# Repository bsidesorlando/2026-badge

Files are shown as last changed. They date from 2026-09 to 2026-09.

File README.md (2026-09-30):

# BSides Orlando 2026 Badge

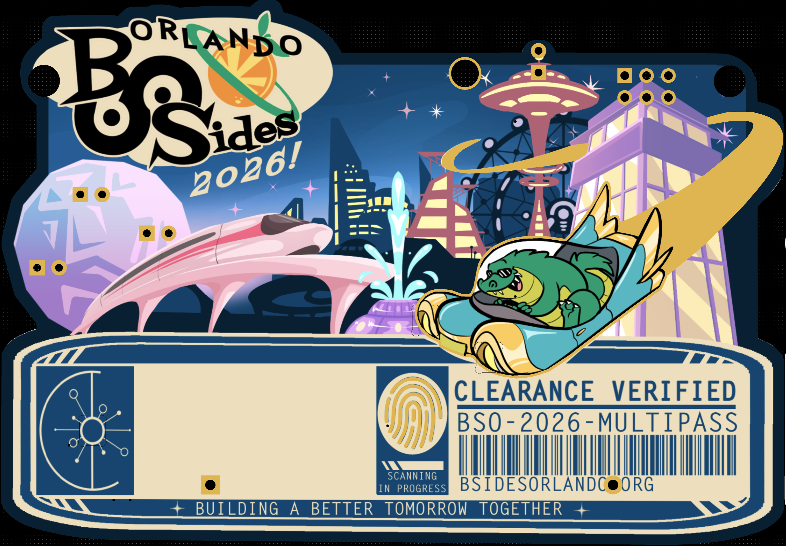
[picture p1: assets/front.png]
Rendering of the front of the BSides Orlando 2026 badge

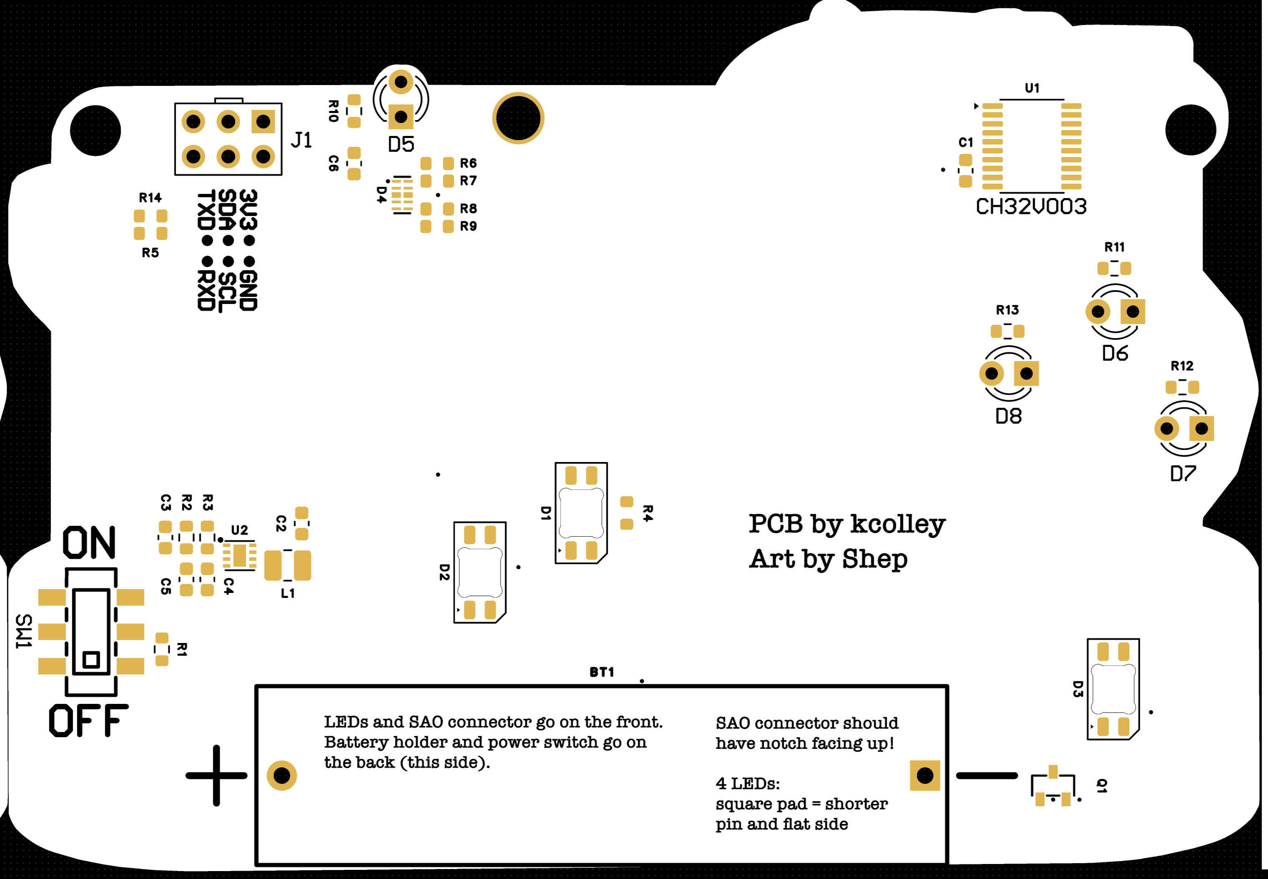
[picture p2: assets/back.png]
Rendering of the back


The electronic badge for BSides Orlando 2026, themed around retro-futurism:
a 1960s World's Fair vision of tomorrow, with Lil Chompy the alligator at
the wheel of a flying car.

- **CH32V003** RISC-V microcontroller, powered by one AAA cell through a
  TPS61021A boost converter.
- **Three SK6812MINI-E RGB LEDs:** the flying car's headlights, and the
  fingerprint scanner indicator.
- **Four self-blinking LEDs:** the tower spire and the geodesic sphere.
- **Two capacitive touch pads:** the fingerprint, and Lil Chompy's head.
- **SAO connector:** the badge is an SAOv3 host on I2C, and GPIO1/GPIO2 carry
  a 115200-baud serial console.
- **Serial console:** runs "Lil Chompy and the World's Fair", a small text
  adventure that doubles as a CTF challenge.

> **Spoilers:** the firmware source contains the CTF solutions and flags.

## Repo layout

| Path | Contents |
| --- | --- |
| `hardware/` | KiCad project (`bsidesorl-v1`), symbol and footprint libraries, and artwork sources |
| `hardware/EasyEDA_Gerber_bsidesorl-v1_2026-08-31.zip` | Gerbers as ordered from JLCPCB |
| `hardware/jlcpcb/` | BOM and CPL as ordered from JLCPCB |
| `hardware/mk_easyeda.py` | Writes an EasyEDA Pro-importable copy of the board |
| `firmware/` | Badge firmware (PlatformIO + [ch32fun](https://github.com/cnlohr/ch32fun)); see [firmware/README.md](firmware/README.md) |

## Firmware quick start

```sh
# saov3-lib's public repo isn't published yet
git submodule update --init

# Build
cd firmware
pio run

# Copy firmware to picorvd-for-badges probe
cp .pio/build/bsorl26/firmware.bin /Volumes/PICORVD/
```

For production, badges are flashed by the standalone programmer build of
[picorvd-for-badges](https://github.com/kjcolley7/picorvd-for-badges)
(an RP2040 probe). It shows up as a USB drive named PICORVD: copy `firmware.bin`
onto it, and set `uart_selftest = 0xB5` in its `CONFIG.TXT` so it triggers the
badge's post-flash self-test over the SWIO pin. Its factory log can be copied
off the same drive as `LOG.CSV`.

## Building your own "programmer SAO"

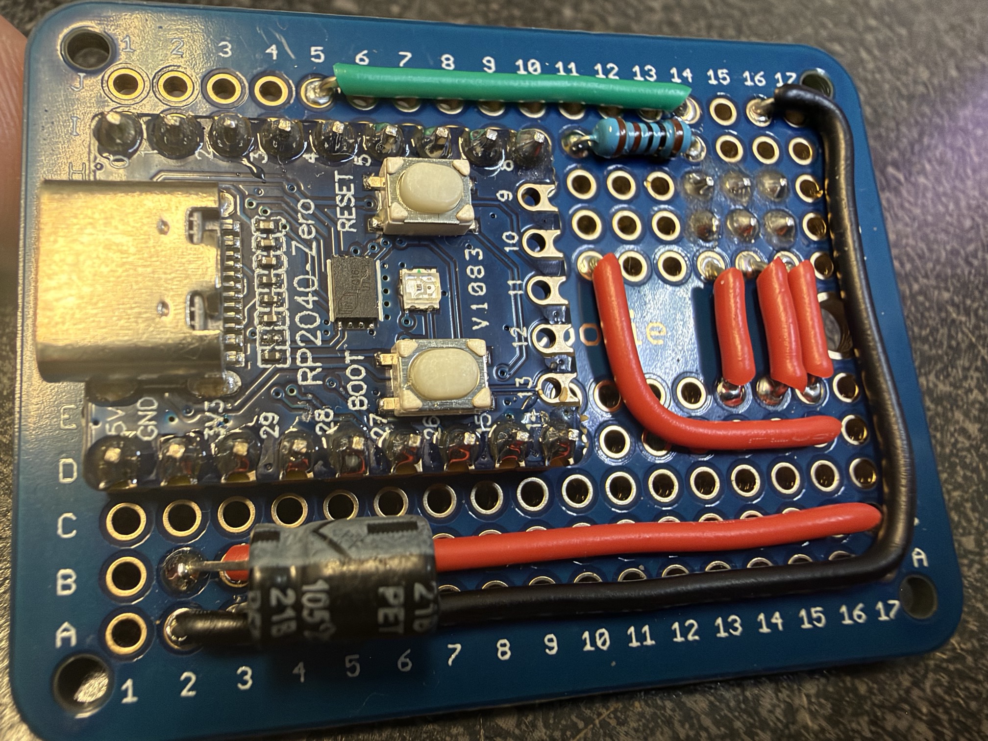
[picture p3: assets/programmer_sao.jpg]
programmer SAO board


> Note that in the picture, the SAO connector is connected on G14-H16. The
> traces on the back were cut between G and H to avoid bridging them. The
> SAO connector is oriented so the top is facing downwards in this photo,
> meaning 3V3 is on G16 and GND is on H16.

For this, you need a Raspberry Pi Pico or compatible board. I used a
[WaveShare RP2040-Zero](https://www.amazon.com/dp/B0DXL12W59) board for the
production programmer SAOs that were used in the soldering village at
BSides Orlando, since they're smaller and cheaper than a Raspberry Pi Pico.
To use as a standalone programmer (where the programmer receives power from
the connected target badge), only three wires are needed: GND, 3v3, and the
Pico's GP4 -> badge's RXD (aka PD1/SWIO). On this SWIO connection, you should
also attach a 1KΩ pull-up resistor to 3v3. This can easily be done on a
breadboard with jumper wires.

You'll need to build the picorvd-for-badges firmware for the probe. The exact
version used on the programmer SAOs at the conference can be found pre-built
here: https://github.com/bsidesorlando/2026-badge/releases/download/v1.0.0/pico_rvd_factory.uf2

To build it yourself for the WaveShare RP2040-Zero board:

```bash
git clone https://github.com/kjcolley7/picorvd-for-badges.git
cd picorvd-for-badges
cmake -B build-zero -G Ninja -DPICO_BOARD=waveshare_rp2040_zero
ninja -C build-zero pico_rvd_factory
```

The above commands create `build-zero/pico_rvd_factory.uf2`, which should be
uploaded to the probe by putting it in BOOTSEL mode and then copying it to the
USB Mass Storage device it exposes. Then, the probe will reboot into the picorvd
firmware and the USB Mass Storage device will re-appear with the name "PICORVD".
Now, it's ready to accept firmware and configuration. You can upload the BSORL
badge firmware from `.pio/build/bsorl26/firmware.bin` (or the pre-built one from
here: https://github.com/bsidesorlando/2026-badge/releases/download/v1.0.0/firmware.bin)
by copying it into the PICORVD volume (which will disappear and reappear as the
probe reboots), and you can also edit the probe's CONFIG.TXT to add
`uart_selftest = 0xB5` (so the probe tells the BSORL badge to enter selftest mode
after programming). At this point, the probe is fully ready to go, either in
standalone mode or tethered mode.

### Standalone mode

This is the mode that was used at BSides Orlando for programming all of the
attendees' badges in the soldering village. It works by powering the probe board
from the target badge itself, and it immediately attempts to program the
connected target upon boot. The badge needs to be powered on so the probe itself
can be powered.

### Tethered mode

This mode works by leaving the probe connected to a host PC over USB. If you
use pico_rvd.uf2 instead of pico_rvd_factory.uf2, the probe won't automatically
program connected badges. Rather, you'll need to manually issue the `factory`
command to the probe over its UART interface. In the pico_rvd_factory.uf2 build,
it will automatically start in factory mode, ready to program any connected
badges.

**NOTE**: Do NOT connect a probe with USB power to a badge while it is switched
on. The power switch should be in the OFF position before connecting a tethered
probe. The badge and the probe will likely have slightly different values than
exactly 3.3v, so there will be some current leakage. Worst case, it could damage
the AAA battery, causing it to leak.

## Credits

PCB and firmware by Kevin Colley. Art by Shep.

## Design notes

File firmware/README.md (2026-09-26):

# BSides Orlando 2026 badge firmware

CH32V003 (RISC-V, 16K flash, 2K RAM) firmware for the production (R1) badge.
Built on [ch32fun](https://github.com/cnlohr/ch32fun).

## Hardware

| Pin | Function |
| --- | --- |
| PC6 | SK6812MINI-E chain (SPI1 MOSI, DMA1 ch3): D1/D2 headlights, D3 scanner |
| PA2 | Fingerprint touch pad (ADC channel 0) |
| PA1 | Lil Chompy's head touch pad (ADC channel 1) |
| PD4 | D5, tower spire LED (self-breathing), open drain, low = on |
| PC4 / PC5 / PC3 | D6 / D7 / D8, geodesic sphere LEDs (self-blinking), open drain, low = on |
| PC1 / PC2 | SAO I2C SDA / SCL, badge is the bus master |
| PD0 | SAO GPIO1, console UART TX (tristated until the console wakes) |
| PD1 | SAO GPIO2, console UART RX, **and SWIO** (the debug pin) |

`src/board.h` has the same map.

## Building and flashing

```sh
git submodule update --init   # first time only — both submodules are pinned
pio run                       # build
pio run -t upload             # build and flash via picorvd probe
```

Flashing goes through `scripts/picorvd_upload.sh`, which drives an RP2040 probe
running [picorvd-for-badges](https://github.com/kjcolley7/picorvd-for-badges) over its GDB and console ports.

## What it does

- **Tower spire**: on, except while an SAOv3 SAO is attached; it sits right
  next to the SAO connector. A plain SAO with no SAOv3 interface on I2C isn't
  detected, so it doesn't turn the spire off.
- **Sphere**: one of its three LEDs is lit. Every few seconds a random dark
  one lights and the old one goes out half a second later. Once the adventure
  is beaten, two are lit and the rotation moves the dark one around instead.
- **Fingerprint pad**: while a finger stays on the pad, the scanner LED
  pulses blue for a random 5–10 s "scan", then flashes green three times:
  clearance verified. Lifting the finger before then fails the scan with
  three red flashes instead. Either way it then returns to idle, a dim,
  slow blue, and a new press always starts a fresh scan.
- **Lil Chompy's head**: tap to cycle the headlight modes, hold for 1 s for
  police lights (see below). The badge always starts in normal mode.
- **HackUCF SAO** (VID 0x0102, PID 0x0001): when it shows up, the headlights
  flash gold, and two things are unlocked for good (saved to flash): the color
  crossfade headlight mode, and a gold instead of blue idle for the fingerprint
  scanner. See `hackucf_tick()` in `main.c`.

### Post-flash self-test

The programmer only needs PD1 (SWIO), which is also the console's RX. After
flashing, let the badge boot (about 100 ms), then send 115200 8N1 on that
pin:

- the single byte `0xB5`, or
- the line `selftest`, ending in CR and/or LF. Send a newline first so any
  noise left on the line from flashing doesn't spoil the match.

Both work with the console asleep, and nothing is sent back. The standalone
programmer build of [picorvd-for-badges](https://github.com/kjcolley7/picorvd-for-badges) sends the byte itself when its
`CONFIG.TXT` has `uart_selftest = 0xB5`. In self-test,
all four self-blinking LEDs are on and all three SK6812s are dim white.
Holding the fingerprint pad turns the scanner red, and holding Chompy's head
turns the headlights green. Holding both at once returns to normal operation.
Nothing pressed during self-test starts a scan or changes the headlight mode.

### Headlight modes

| Mode | What it does | How to get there |
| --- | --- | --- |
| normal | warm yellow-orange at about 8/255; every 8–12 s either one headlight blinks orange as a turn signal for 5–10 s, or (1 time in 4) both flash their high beams | power-on; tap from rainbow or police |
| hazards | both blink orange, ~85 flashes/min | tap from normal |
| rainbow | hue cycle, headlights half a wheel apart | tap from hazards, once the adventure is beaten (the badge switches to it the moment it's unlocked) |
| police | red/blue double-strobe | hold Chompy's head for 1 s from normal, hazards or rainbow |
| color crossfade | the headlights take turns: one fades in on a new random hue while the other fades out, 1 s per fade | tap from police, once a Hack@UCF SAO has ever been attached |

A 1 s hold switches between the tap modes (normal, hazards, rainbow) and
the hold modes (police, color crossfade), landing on whichever mode was
last used on that side: police the first time, and back to hazards if
that's where you held from. A tap in police toggles to the crossfade and
back once it's unlocked; before that, a tap in police returns to normal.

A tap acts on release, so the start of a hold never also counts as a tap.
All SK6812 output is capped at 48/255 (`HEADLIGHT_BRIGHTNESS` and
`SCANNER_BRIGHTNESS` in `src/rgb.c`); high beams and signals run at that cap.

## Serial console and CTF

Plug a 3.3 V USB-serial adapter into the SAO header (badge TX = GPIO1,
RX = GPIO2, plus GND), open it at **115200 8N1**, and press Enter.

The SAO spec says a host that hasn't negotiated a GPIO mode must drive nothing
on those pins. So TX stays tristated until the console wakes, which needs a
clean CR/LF on RX while **no SAO answers on I2C**. It stays awake until an SAO
appears or the badge resets. RX has the weak internal pull-up on, so an empty
header idles high instead of floating.

The console runs **Lil Chompy and the World's Fair**, a small retro-futurist
text adventure and the badge's CTF challenge. It uses the badge hardware:
you hold your finger on the real fingerprint pad to get through the
fairgrounds gate, and tap Chompy's real head to wake him. Then you have to
find the flight passkey he dropped before he'll fly you up the Sky Spike.
The game only hints at the hardware interactions. The walkthrough is at the
top of `src/game.c`.

Commands: `LOOK [thing]` (or `LOOK AT`), directions, `FLY`, `SAY`,
`STATUS`, `RESTART`, `RESET`. Words match on their first 7 letters. `RESET`
wipes the settings page (every solve and unlock) and reboots the badge.

The game tracks which way the player is facing (north at the start), and the
headlights signal each move relative to it: a turn signal for a left or right
turn, the brights straight ahead, the hazards for doubling back. Up, down and
`FLY` don't change the facing, and blocked moves don't signal.

Beating it prints the flag, which players submit on the CTFd site; the badge
doesn't take flags. The solve is saved to flash, lights a second sphere LED, and
unlocks rainbow headlights (switching to them right away). `STATUS` lists
what's solved and what's unlocked.

Beating it also unlocks `PEEK <hex address>` (`0x` optional),
which reads one 32-bit word and prints it as `0x08000000: 0xAABBCCDD`. A player
who looks up the CH32V003 memory map can dump the firmware with it. Before the
solve, `PEEK` is treated as an unknown word. There are no guard rails: a read
from an address the chip doesn't implement faults. The fault handler in
`src/console.c` prints `*** CRASH: mcause <cause> -- rebooting ***` and resets
the badge (5 is a load access fault, 4 a misaligned load). The console needs another Enter
afterwards, and the game starts over, though the saved solve survives.

The one exception is the second flag, `sun{l00k_1n_th3_m1rr0r}`
(`ctf_mirror_flag` in `src/ctf.c`). It sits alone in its own 64-byte flash
page, and `PEEK` answers `ACCESS DENIED` for that page at its low boot-mirror
address (`0x0000xxxx`). The same bytes read fine at the real flash address,
`0x08000000` plus the same offset. Its offset moves whenever the code changes,
so players have to find it in their dump.

The game prints its flag, so `src/ctf.c` holds an XOR-obfuscated copy. To
change it, regenerate the array with `scripts/ctf_flag.py 0 '<flag>'`.

### Adding to the game

- **Text** goes in `src/game_text.txt`, one `@NAME` block per message, printed
  with `say(T_NAME)`. `scripts/gen_text.py` compresses it at build time
  (byte-pair encoding, about 35% smaller) into `game_text.h` in the build
  directory.
- **Rooms**: add an entry to `enum room`, an `@ROOM_` message in the same
  position, and an exits row. Special behavior goes in the verb handlers.
- **Words**: add them to `enum word` and `vocab[]` (8 characters max).
- **Challenges**: add an ID in `src/ctf.h`, a flag and name in `src/ctf.c`,
  and call `ctf_mark_solved()` when it's solved.
- **Try it on your laptop**: `test/host/run.sh` builds the real `game.c` and
  `ctf.c` against stubs and plays in the terminal. `!scan` and `!chompy`
  stand in for the touch pads. `test/host/run.sh < test/host/walkthrough.txt`
  replays a full solve.

### Flash budget

About 16.3K of the 16,320 usable bytes are used; the last 64-byte page holds
settings. Game text packs to about two thirds of its size.
Every build prints both numbers. The linker script is trimmed so the build
fails rather than growing into the settings page.

If space runs out, the cheapest wins are, roughly in order:

- move short string literals left in `game.c` into the catalog;
- drop a headlight mode;
- turn logging off in ch32fun (`FUNCONF_USE_DEBUGPRINTF 0`, about 25 bytes,
  but `TOUCH_DEBUG` then has nowhere to print).

## SAOv3 host

The badge implements the host side of the SAOv3 draft spec, using
`saov3-lib/host/saoh_core` over the CH32V003's hardware I2C1 master
(`src/i2c_host.c`). Timeouts and stuck-bus recovery are done in software.

- Full discovery scan about 500 ms after boot: static SAO detection magic plus
  SMBus ARP enumeration.
- Hot-plug: a cheap ARP `scan_new` every 1 s and a full ARP rescan every 15 s.
  While nothing is attached, a full reset scan also runs every 2 s: static
  (non-ARP) SAOs only show up in one of those.
  Every enumerated SAO also gets a liveness check about every 0.5 s, since
  static SAOs have no removal event.
- Enumeration: SAOv3 magic/version check, VID/PID, default GPIO mode written
  per spec, class interface discovery.
- **SAO LEDs are not taken over automatically.** Call
  `sao_host_set_led_takeover(1)` to mirror the headlight colors across every
  LED-capable SAO's string (up to 16 LEDs, 10 Hz), and `0` to hand them back.
- `sao_host_find(vid, pid)` reports whether a particular SAO is attached.

## Layout

- `src/main.c`: main loop, RNG, HackUCF SAO hook, self-test
- `src/board.h`: pin map
- `src/rgb.c`: SK6812 headlight modes, scanner animation, event flashes
- `src/beacons.c`: spire and sphere LEDs
- `src/touch.c`: both capacitive pads
- `src/settings.c`: persistent settings: the last flash page holds the magic
  `BSO_2026` (8 bytes), then one `unlocks` byte (bits 0..6 for CTF solves, bit
  7 for the Hack@UCF crossfade), then `FF`
- `src/console.c`: UART console, line editor, wake/sleep arbitration
- `src/game.c` and `src/game_text.txt`: the text adventure
- `src/ctf.c`: challenge table, flag printing, solve rewards
- `src/sao_host.c`: SAO discovery, enumeration, liveness, optional LED mirroring
- `src/i2c_host.c`: I2C1 master HAL under the SAOv3 host library
- `scripts/`: linker script generator, text compressor, flag obfuscator, picorvd flash helpers
- `test/host/`: host build of the adventure
- `ch32fun/`, `saov3-lib/`: pinned submodules

## Constraints and gotchas

- **PD1 is SWIO.** The console only ever listens on it, and the SDI debug
  function stays enabled, so debugging keeps working. While a probe is
  talking, the console sees that traffic as noise, which is dropped as
  framing errors.
- **The adventure's flag is only obfuscated**, because the badge has to print
  it. SWIO is on the SAO connector, so anyone with a WCH-Link can dump flash
  and decode it, or set their own badge's solved bits. Enable flash read
  protection on production badges if that matters.
- I2C pins go to AF **after** the peripheral is enabled. An AF open-drain pin
  whose peripheral is disabled drags the bus low.
- Touch thresholds (`pads[]` in `src/touch.c`) are guesses until tuned on real
  hardware; Chompy's pad is much smaller than the fingerprint. Enable
  `TOUCH_DEBUG` and watch the SWIO console.
- Host library logging is compiled to `LOGL_NONE`, and `log.c`/`err.c` are
  excluded from the build. Re-add both to debug enumeration.
- No float anywhere; pattern math is integer. RV32EC has no hardware multiply,
  which is fine at the 10 ms tick but keep it out of ISRs.
- The SWIO hardfault dump is off (`src/funconfig.h`) to save flash. Turn it
  back on when chasing a crash.

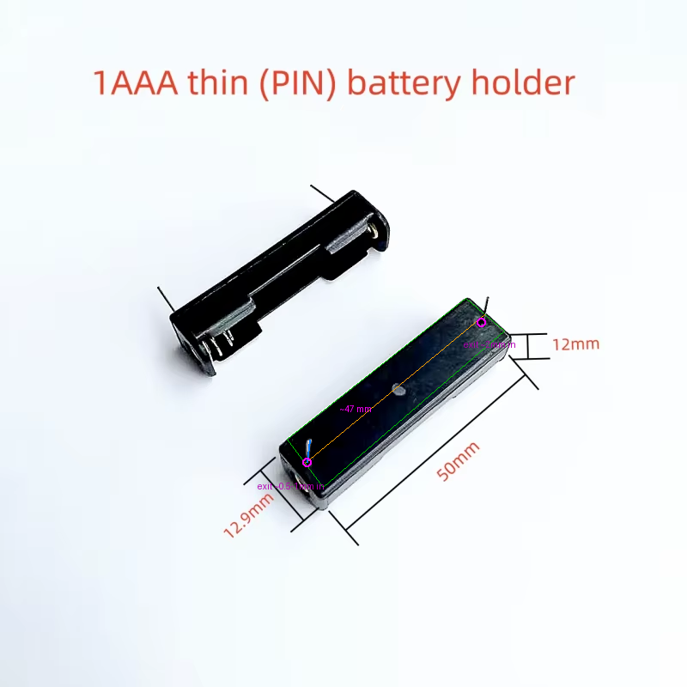
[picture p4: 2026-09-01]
hardware/aaa_holder_pin_spacing_estimate.png

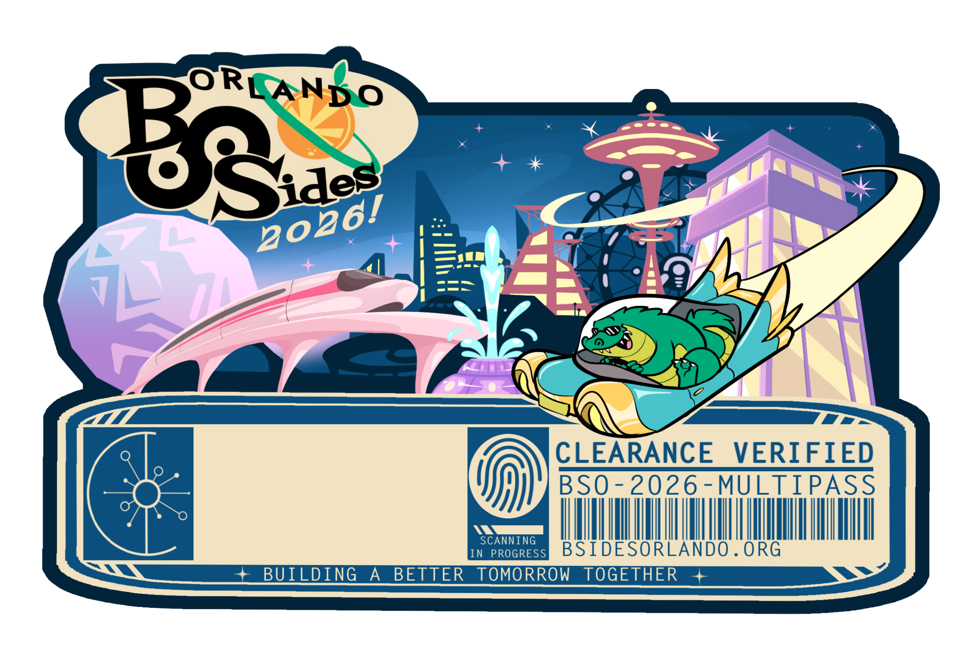
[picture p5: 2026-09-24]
hardware/uv_art.png

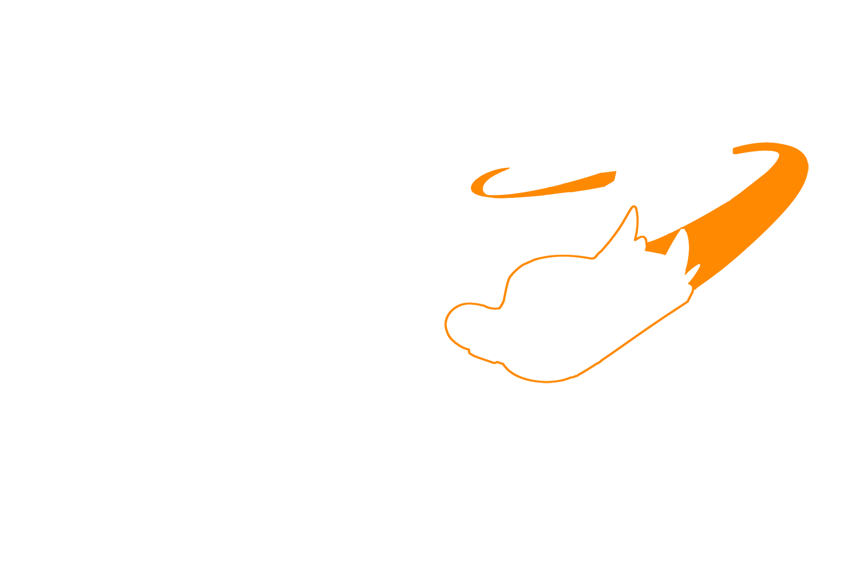
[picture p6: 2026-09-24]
hardware/F.Mask.png

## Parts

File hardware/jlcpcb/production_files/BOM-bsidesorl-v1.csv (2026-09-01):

Comment | Designator | Footprint | LCSC | Quantity
100K | R3 | R_0603_1608Metric | C25803 | 1
100nF | C1 | C_0603_1608Metric | C14663 | 1
10K | R14,R5 | R_0603 | C25804 | 2
10pF | C3 | C_0603_1608Metric | C1634 | 1
1M | R1 | R_0603_1608Metric | C22935 | 1
1uH | L1 | L_1008_2520Metric | C5832356 | 1
2.2uF | C6 | C_0603_1608Metric | C23630 | 1
22uF | C2,C4,C5 | C_0603_1608Metric | C59461 | 3
316K | R2 | R_0603_1608Metric | C25814 | 1
33R | R4,R6,R7,R8,R9 | R_0603 | C23140 | 5
470R | R10,R11,R12,R13 | R_0603_1608Metric | C23179 | 4
CH32V003F4P6 | U1 | TSSOP-20_4.4x6.5mm_P0.65mm | C5187096 | 1
SI2302S | Q1 | SOT-23-3_L2.9-W1.3-P1.90-LS2.4-BR | C22463594 | 1
SK6812MINI-E | D1,D2,D3 | LED_SK6812MINI-E_3.2x2.8mm_P1.5mm_ReverseMount | C5149201 | 3
TPD4E05U06DQAR_C22390021 | D4 | DFN2510-10_L2.5-W1.0-P0.50-BL | C22390021 | 1
TPS61021ADSGR | U2 | WSON-8_L2.0-W2.0-P0.50-TL-EP | C193037 | 1

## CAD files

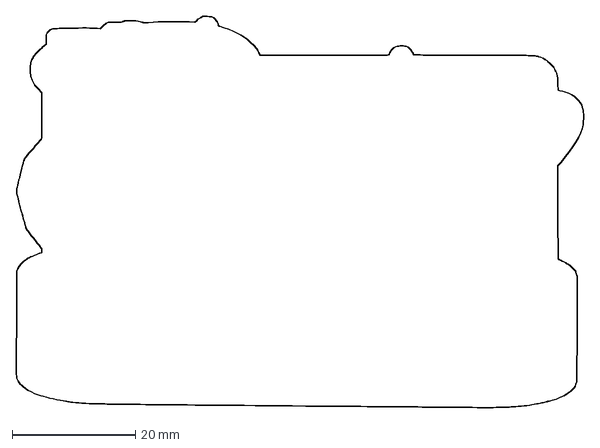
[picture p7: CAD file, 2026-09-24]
hardware/Edge.Cuts.outline.dxf
92.0 x 63.4 mm

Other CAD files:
hardware/F.Mask.fingerprint.dxf

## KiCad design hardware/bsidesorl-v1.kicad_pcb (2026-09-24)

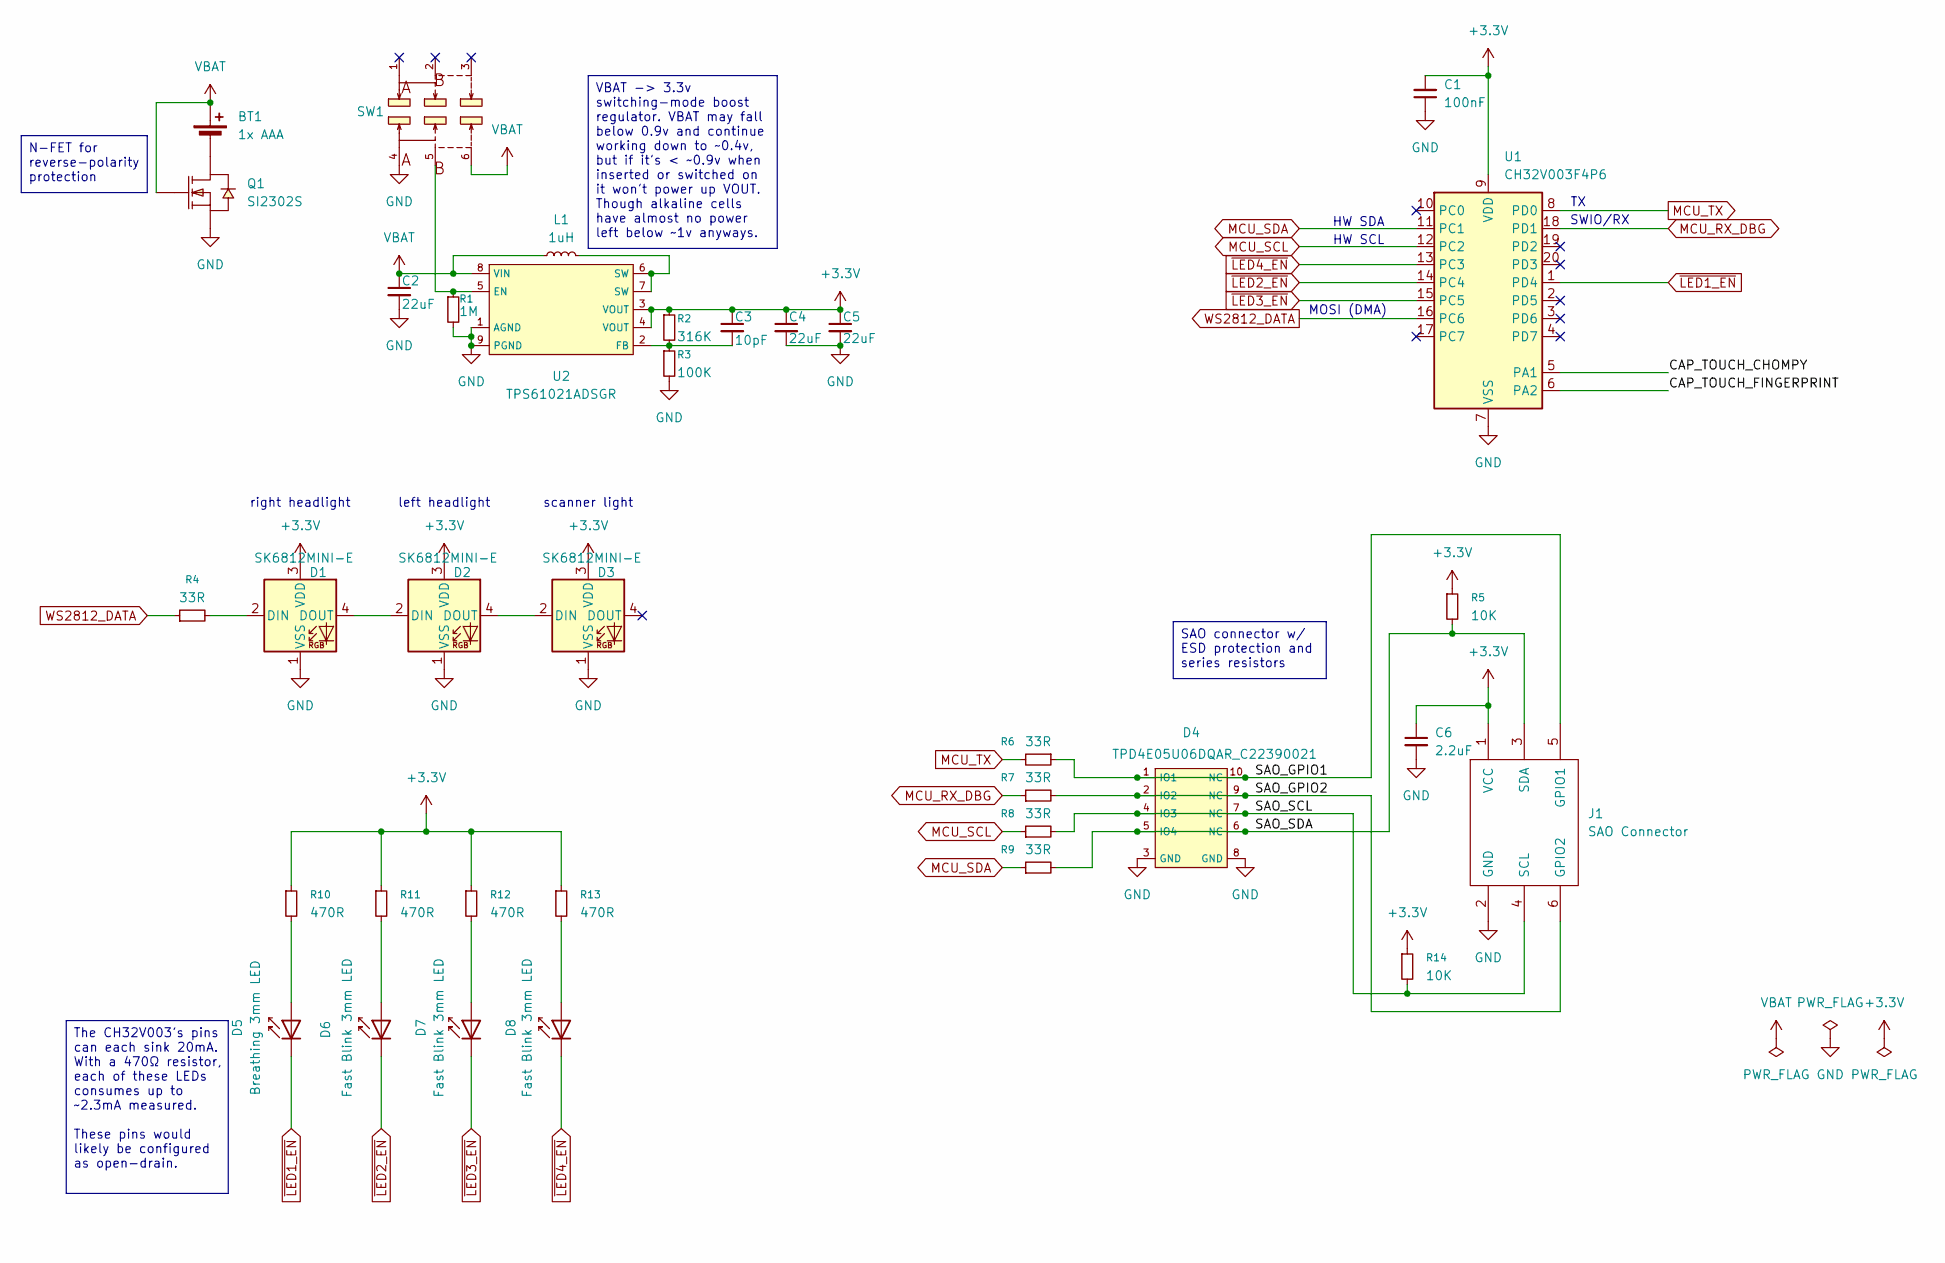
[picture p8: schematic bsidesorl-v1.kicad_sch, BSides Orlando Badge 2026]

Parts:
BT1: 1x AAA; BAT-TH_BH-AAA-1X
C1: 100nF; C_0603_1608Metric; LCSC C14663
C2, C4, C5: 22uF; C_0603_1608Metric
C3: 10pF; C_0603_1608Metric
C6: 2.2uF; C_0603_1608Metric; LCSC C23630
D1, D2, D3: SK6812MINI-E; LED_SK6812MINI-E_3.2x2.8mm_P1.5mm_ReverseMount
D4: TPD4E05U06DQAR_C22390021; DFN2510-10_L2.5-W1.0-P0.50-BL; LCSC C22390021
D5: Breathing 3mm LED; LED_D3.0mm_IRBlack
D6, D7, D8: Fast Blink 3mm LED; LED_D3.0mm_IRBlack
J1: SAO Connector; PinSocket_2x03_P2.54mm_Vertical
L1: 1uH; L_1008_2520Metric
Q1: SI2302S; SOT-23-3_L2.9-W1.3-P1.90-LS2.4-BR; LCSC C22463594
R1: 1M; R_0603_1608Metric
R2: 316K; R_0603_1608Metric
R3: 100K; R_0603_1608Metric
R4: 33R; R_0603
R5, R14: 10K; R_0603; LCSC C25804
R6, R7, R8, R9: 33R; R_0603; LCSC C23140
R10, R11, R12, R13: 470R; R_0603_1608Metric; LCSC C23179
SW1: MST22D18G2_125; SW-SMD_MST22D18G2; LCSC C2906280
U1: CH32V003F4P6; TSSOP-20_4.4x6.5mm_P0.65mm; LCSC C5187096
U2: TPS61021ADSGR; WSON-8_L2.0-W2.0-P0.50-TL-EP; LCSC C193037

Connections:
+3.3V: C1.2, C3.1, C4.1, C5.1, C6.1, D1.3 (VDD), D2.3 (VDD), D3.3 (VDD), J1.1 (VCC), R2.1, R5.1, R10.1, R11.1, R12.1, R13.1, R14.1, U1.9 (VDD), U2.3 (VOUT), U2.4 (VOUT)
/CAP_TOUCH_CHOMPY: U1.5 (PA1)
/CAP_TOUCH_FINGERPRINT: U1.6 (PA2)
/SAO_GPIO1: D4.1 (IO1), D4.10 (NC), J1.5 (GPIO1), R6.1
/SAO_GPIO2: D4.2 (IO2), D4.9 (NC), J1.6 (GPIO2), R7.2
/SAO_SCL: D4.4 (IO3), D4.7 (NC), J1.4 (SCL), R8.2, R14.2
/SAO_SDA: D4.5 (IO4), D4.6 (NC), J1.3 (SDA), R5.2, R9.2
GND: C1.1, C2.2, C4.2, C5.2, C6.2, D1.1 (VSS), D2.1 (VSS), D3.1 (VSS), D4.3 (GND), D4.8 (GND), J1.2 (GND), Q1.2 (S), R1.2, R3.2, SW1.4, U1.7 (VSS), U2.1 (AGND), U2.9 (PGND)
MCU_RX_DBG: R7.1, U1.18 (PD1)
MCU_SCL: R8.1, U1.12 (PC2)
MCU_SDA: R9.1, U1.11 (PC1)
MCU_TX: R6.2, U1.8 (PD0)
unnamed: BT1.2 (-), Q1.3 (D)
unnamed: D1.2 (DIN), R4.2
unnamed: D1.4 (DOUT), D2.2 (DIN)
unnamed: D2.4 (DOUT), D3.2 (DIN)
unnamed: D5.2 (A), R10.2
unnamed: D6.2 (A), R11.2
unnamed: D7.2 (A), R12.2
unnamed: D8.2 (A), R13.2
unnamed: L1.2, U2.6 (SW), U2.7 (SW)
unnamed: R1.1, SW1.5, U2.5 (EN)
unnamed: C3.2, R2.2, R3.1, U2.2 (FB)
VBAT: BT1.1 (+), C2.1, L1.1, Q1.1 (G), SW1.6, U2.8 (VIN)
WS2812_DATA: R4.1, U1.16 (PC6)
~LED1_EN: D5.1 (K), U1.1 (PD4)
~LED2_EN: D6.1 (K), U1.14 (PC4)
~LED3_EN: D7.1 (K), U1.15 (PC5)
~LED4_EN: D8.1 (K), U1.13 (PC3)

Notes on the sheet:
left headlight
SWIO/RX
MOSI (DMA)
scanner light
HW SCL
right headlight
HW SDA
VBAT -> 3.3v switching-mode boost regulator. VBAT may fall below 0.9v and continue working down to ~0.4v, but if it's < ~0.9v when inserted or switched on it won't power up VOUT. Though alkaline cells have almost no power left below ~1v anyways.
The CH32V003's pins can each sink 20mA. With a 470Ω resistor, each of these LEDs consumes up to ~2.3mA measured. These pins would likely be configured as open-drain.
SAO connector w/ ESD protection and series resistors
N-FET for reverse-polarity protection

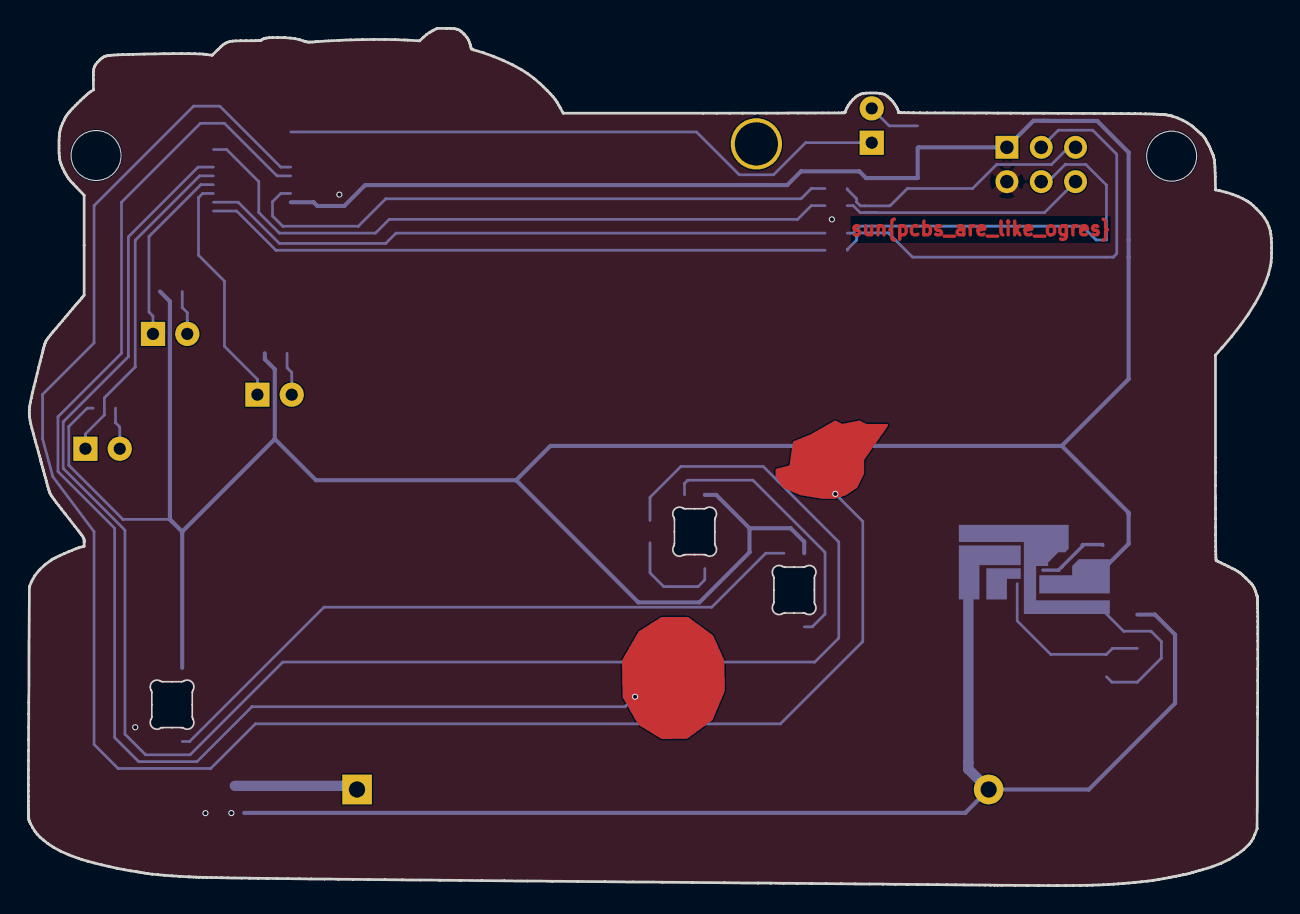
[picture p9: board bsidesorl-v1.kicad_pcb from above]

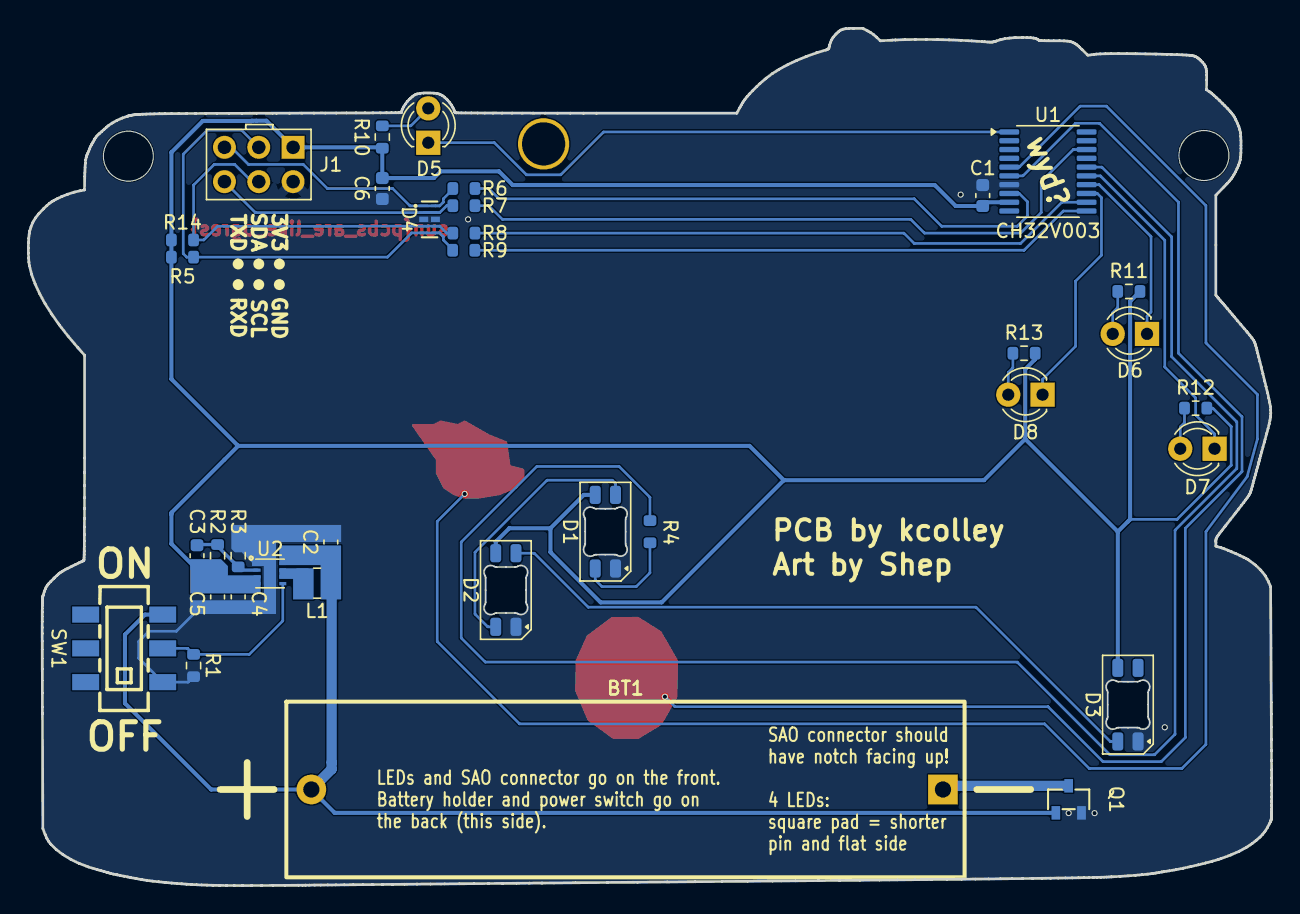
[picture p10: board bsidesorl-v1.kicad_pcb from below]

Board: 2 copper layers, 92.0 x 63.4 mm, 37 parts (30 on the bottom side), 27 nets.

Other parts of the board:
HOLE1, HOLE2: LanyardHole

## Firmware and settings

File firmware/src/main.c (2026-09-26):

// BSides Orlando 2026 badge -- CH32V003 firmware for the production (R1) PCB.
//
// What the badge does (pin map in board.h):
//   - Tower spire LED on, except while an SAO is attached (it sits right by
//     the SAO connector); the geodesic sphere keeps one of its three
//     LEDs lit, handing off every few seconds -- more of them for every CTF
//     challenge solved (beacons.c, ctf.c).
//   - Fingerprint pad: hold a finger on it and the scanner LED pulses blue
//     through a 5-10 s "scan", then flashes green: clearance verified.
//     Lifting early fails the scan with red flashes (rgb.c).
//   - Lil Chompy's head: tap to cycle the flying car's headlight modes
//     (normal, hazards, and rainbow once a challenge is solved), hold for
//     police lights (rgb.c). A Hack@UCF SAO unlocks a color crossfade.
//   - SAO connector: SAOv3 host on I2C (sao_host.c), plus a serial console on
//     the GPIO pins running a text adventure CTF (console.c, game.c).
//   - Post-flash self-test, triggered over the console RX pin (selftest.h).

#include "ch32fun.h"

#include "beacons.h"
#include "console.h"
#include "ctf.h"
#include "game.h"
#include "rgb.h"
#include "sao_host.h"
#include "selftest.h"
#include "settings.h"
#include "touch.h"
#include "util.h"

// ---------- RNG ----------

static uint32_t rng_state = 1;

void rand_seed(uint32_t seed)
{
	rng_state = seed ? seed : 1;   // xorshift has a fixed point at zero
}

uint32_t rand_u32(void)
{
	uint32_t x = rng_state;

	x ^= x << 13;
	x ^= x >> 17;
	x ^= x << 5;
	rng_state = x;
	return x;
}

// ---------- HackUCF SAO ----------
// When a Hack@UCF SAO shows up: a gold flash of the headlights, and a
// permanent unlock of the color crossfade and a gold fingerprint-scanner
// idle.
static void hackucf_tick(void)
{
	static uint8_t present;
	uint8_t now = sao_host_find(SAO_VID_HACKUCF, SAO_PID_HACKUCF);

	if (now && !present) {
		rgb_flash(255, 170, 0, 3);
		if (!(settings.unlocks & UNLOCK_HACKUCF_FADE)) {
			settings.unlocks |= UNLOCK_HACKUCF_FADE;
			settings_save();
		}
	}

	rgb_scan_gold(settings.unlocks & UNLOCK_HACKUCF_FADE);
	present = now;
}

// ---------- Lil Chompy's head ----------
// A tap acts on release, so the start of a hold doesn't also count as a tap;
// a hold acts once, when it reaches CHOMPY_HOLD_TICKS.

#define CHOMPY_HOLD_TICKS MS_TICKS(1000)

// Ticks the pad has been held, 0 when released. Parked past the threshold
// when a press must be ignored until it lets go (see selftest_tick).
static uint16_t chompy_ticks;

static void chompy_tick(uint8_t taps)
{
	// The adventure's "wake Chompy" reacts to any touch, right away.
	if (taps & (1u << TOUCH_CHOMPY))
		game_on_chompy_tap();

	if (touch_held() & (1u << TOUCH_CHOMPY)) {
		if (chompy_ticks <= CHOMPY_HOLD_TICKS && ++chompy_ticks == CHOMPY_HOLD_TICKS)
			rgb_mode_hold();
		return;
	}

	if (chompy_ticks && chompy_ticks < CHOMPY_HOLD_TICKS)
		rgb_mode_next();
	chompy_ticks = 0;
}

// ---------- self-test ----------

#define PADS_BOTH ((1u << TOUCH_FINGERPRINT) | (1u << TOUCH_CHOMPY))

static uint8_t selftest;

void selftest_start(void)
{
	selftest = 1;
	beacons_force_all(1);
	rgb_selftest(1, 0, 0);
}

// Runs instead of the normal touch handling while in self-test, so no press
// made here starts a scan or changes the headlight mode.
static void selftest_tick(void)
{
	uint8_t held = touch_held();

	if (held == PADS_BOTH) {
		selftest = 0;
		beacons_force_all(0);
		rgb_selftest(0, 0, 0);
		// The exit press is still down; don't let its release count as a tap.
		chompy_ticks = CHOMPY_HOLD_TICKS + 1;
		return;
	}

	rgb_selftest(1, held & (1u << TOUCH_FINGERPRINT), held & (1u << TOUCH_CHOMPY));
}

// ---------- main ----------

int main(void)
{
	SystemInit();

	settings_load();

	beacons_init();
	touch_init();
	rand_seed(ESIG->UNIID1 ^ ESIG->UNIID2 ^ ESIG->UNIID3 ^ touch_noise());
	ctf_init();
	rgb_init();
	sao_host_init();
	con_init();

	while (1) {
		uint8_t taps = touch_tick();

		if (selftest) {
			selftest_tick();
		}
		else {
			if (taps & (1u << TOUCH_FINGERPRINT))
				rgb_scan_start();
			rgb_scan_finger(touch_held() & (1u << TOUCH_FINGERPRINT));

			chompy_tick(taps);
		}

		if (rgb_tick())
			game_on_scan_verified();

		beacons_set_spire(sao_host_count() == 0);
		beacons_tick();

		// Discovery scans, liveness checks, and (when taken over) SAO LED
		// mirroring; rate-limited internally.
		sao_host_task(TICK_MS);
		hackucf_tick();

		con_tick();
		settings_tick();

		Delay_Ms(TICK_MS);
	}
}

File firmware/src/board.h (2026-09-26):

#ifndef _BOARD_H
#define _BOARD_H

// Pin map for the production (R1) PCB. See hardware/bsidesorl-v1.kicad_sch.

// SK6812MINI-E chain on PC6 (SPI1 MOSI, streamed by DMA1 channel 3). Chain
// order is D1 -> D2 -> D3.
#define RGB_HEADLIGHT_L 0    // D1, flying car headlight (left, facing the badge)
#define RGB_HEADLIGHT_R 1    // D2, flying car headlight (right)
#define RGB_SCANNER     2    // D3, the "SCANNING IN PROGRESS" indicator
#define RGB_COUNT       3

// Self-blinking 3mm LEDs. Each MCU pin sits in the LED's ground return path,
// so these are open drain: pull low to light, release to turn off.
#define PIN_SPIRE   PD4      // D5, breathing LED at the top of the tower spire
// D6-D8, fast-blink LEDs on the geodesic sphere:
#define PIN_SPHERE0 PC4      // D6
#define PIN_SPHERE1 PC5      // D7
#define PIN_SPHERE2 PC3      // D8

// Capacitive touch pads (ADC slope sensing).
#define TOUCH_FINGERPRINT_PIN 2    // PA2, ADC channel 0
#define TOUCH_FINGERPRINT_ADC 0
#define TOUCH_CHOMPY_PIN      1    // PA1, ADC channel 1 (Lil Chompy's head)
#define TOUCH_CHOMPY_ADC      1

// SAO connector:
//   PC1/PC2 -> SDA/SCL (badge is the SMBus master)
//   PD0 -> GPIO1, doubles as the console's UART TX (USART1 partial remap 1)
//   PD1 -> GPIO2, doubles as the console's UART RX -- and is SWIO (debug)

#endif

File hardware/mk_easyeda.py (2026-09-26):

#!/usr/bin/env python3
"""Write an EasyEDA-import-friendly copy of the KiCad board.

EasyEDA Pro's KiCad importer (chameleon/*/js/convert-node-server.js) was
written against an older KiCad file format.  Two things in a modern
KiCad 9/10 board silently break it.  This script patches both, in a copy.

1. Missing net table  ->  netless tracks, vias and pours
--------------------------------------------------------
KiCad 10 no longer emits the top-level `(net N "name")` table; objects carry
the net NAME inline, e.g. `(segment ... (net "GND"))`.  The importer still
builds its lookup from that table:

    parseNet(e){ for(...) this.netObj[e[1]] = ec(e[2])[0] }
    parseTrack: ... h[0]==="net" ? r = this.netObj[h[1]] : ...

With no `(net ...)` elements, netObj stays empty and every track, via and pour
imports with an EMPTY net.  Netless copper pours have nothing to clear around,
so they flood-fill -- which is what buries the routing under near-solid copper.

The importer's parser keeps the quotes on string tokens (hence the
`.replace(/"/g,"")` calls all over it), so a declaration keyed by NAME --
`(net "GND" "GND")` -- lands in netObj under exactly the token objects use.

2. `(fill yes)` vs `(fill solid)`  ->  hollow polygons
------------------------------------------------------
KiCad <= 6 wrote `(fill solid)` / `(fill none)` on gr_poly; KiCad 7+ writes
`(fill yes)` / `(fill no)`.  The importer still tests for the old spelling:

    parsePoly: ... else if(y[0]==="fill") p = (y[1]||"").toLowerCase()=="solid";
               ... return p ? d.convertToFillRegion() : d.convertToLine()

`"yes" != "solid"`, so every filled polygon is imported as an unfilled outline
-- copper polygons show up hollow / "skeleton style".

Only the standalone `(fill yes)` / `(fill no)` forms are rewritten.  Zones use
a multi-line `(fill yes (thermal_gap ...) ...)` that the importer parses by
iterating children, and it must be left alone -- the regexes below anchor on
the closing paren so they cannot match it.

What does NOT need changing: layer numbering
--------------------------------------------
EasyEDA selects its layer table from the file version:

    version.length < 8 ? (version === "3" ? init2() : init1())
                       : (version < "20241129" ? init1() : init3())

init3 already matches KiCad 9/10 numbering (B.Cu=2, Edge.Cuts=25, F.SilkS=5).
Renumbering layers to the legacy init1 scheme BREAKS the import -- id 37 does
not exist in init3, and parseLayers throws
"Cannot read properties of null (reading 'hashId')", surfacing in the UI as
the unhelpful "Convert abnormalities, wrong code:encoding-error".
(That error code is the encode/export half of the pipeline failing, not a
character-encoding problem.)

Usage
-----
    ./mk_easyeda.py [source.kicad_pcb] [dest.kicad_pcb]

Defaults to bsidesorl-v1.kicad_pcb -> bsidesorl-v1-easyeda.kicad_pcb, both next
to this script (in hardware/).

The output is a ONE-WAY export artifact: re-run after every board change, and
do not open it in KiCad (KiCad will rewrite what it does not recognize).

Verifying without the GUI
-------------------------
EasyEDA ships its converter as a runnable CLI, so an import can be tested
headlessly:

    CONV="/Applications/EasyEDA-Pro.app/Contents/Resources/app/assets/chameleon/<ver>/js/convert-node-server.js"
    node "$CONV" --cmd conversion --params-path params.json

with params.json:

    {"decodingOptions": {"decodingType": "kicad",
                         "decodingFilePath": "<abs path to the -easyeda .kicad_pcb>",
                         "projectName": "bsidesorl-v1", "projectType": "normal"},
     "encodingOptions": {"encodingType": "easyeda-pro",
                         "savingDirPath": "<abs output dir>",
                         "savingFileName": "out", "encoderOptions": {}}}

The resulting .epro is a zip; PCB/*.epcb holds one JSON array per shape:
  track  ["LINE", id, ?, net, layer, x1,y1, x2,y2, width, ?]   layer 2 = Bottom
  filled ["FILL", ...]      hollow ["POLY", ...]
Confirm nets are non-empty and that copper shapes are FILL, not POLY.
"""
import re
import sys
from pathlib import Path

HERE = Path(__file__).resolve().parent
DEFAULT_SRC = HERE / 'bsidesorl-v1.kicad_pcb'

# EasyEDA picks init3 (KiCad 9/10 layer numbering) at or above this file version.
INIT3_MIN_VERSION = "20241129"


def build(src_path: Path, dst_path: Path) -> int:
    src = src_path.read_text()

    m = re.search(r'\(version (\d+)\)', src)
    if not m:
        sys.exit(f"{src_path}: no (version ...) token -- is this a .kicad_pcb?")
    ver = m.group(1)
    if ver < INIT3_MIN_VERSION:
        sys.exit(f"{src_path}: version {ver} predates KiCad 9 layer numbering, so "
                 f"EasyEDA uses its init1 table; this script assumes init3.")

    # Top-level (net ...) declarations, either KiCad's numeric form or the
    # name-keyed one this script writes. Either way there is nothing to add,
    # and re-running on our own output would duplicate every entry.
    existing = len(re.findall(r'\n\t\(net (?:\d+|")', src))
    if existing:
        sys.exit(f"{src_path}: already has {existing} top-level (net ...) "
                 f"declarations -- nothing to inject. Run this on the source "
                 f"board, not on a generated -easyeda copy.")

    nets = sorted(set(re.findall(r'\(net "([^"]*)"\)', src)))
    if not nets:
        sys.exit(f"{src_path}: found no (net \"name\") references.")
    decl = "".join(f'\t(net "{n}" "{n}")\n' for n in nets)

    # Insert straight after the (setup ...) block, so nets are parsed before any
    # footprint / segment / zone that references them.
    setup = re.search(r'\n\t\(setup\n', src)
    if not setup:
        sys.exit(f"{src_path}: no (setup ...) block to anchor the insertion to.")
    depth = 0
    end = None
    for i in range(setup.start() + 1, len(src)):
        if src[i] == '(':
            depth += 1
        elif src[i] == ')':
            depth -= 1
            if depth == 0:
                end = i + 1
                break
    if end is None:
        sys.exit(f"{src_path}: unbalanced parentheses in (setup ...).")

    out = src[:end] + "\n" + decl.rstrip('\n') + src[end:]

    if out.count('(') != out.count(')'):
        sys.exit("refusing to write: parentheses unbalanced after net injection")
    if not (src[:end] == out[:end] and src[end:] == out[len(out) - len(src[end:]):]):
        sys.exit("refusing to write: bytes outside the insertion point changed")
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

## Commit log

2026-08-04 Added missing switch footprint
    [bsidesorl-v1.kicad_pcb, bsidesorl-v1.kicad_sch]
2026-08-04 Moved an LED
    [bsidesorl-v1.kicad_pcb]
2026-08-04 Add mounting hold for lanyard
    [bsidesorl-v1.kicad_pcb]
2026-08-04 Remove KiCad lock files from git
2026-08-04 Add MCU and clean up schematic
    [bsidesorl-v1.kicad_sch]
2026-08-05 Layout done for current components
    [bsidesorl-v1.kicad_pcb]
2026-08-13 Add I2C pull-ups, SAO ESD & series resistors, local libs
    [bsidesorl-v1.kicad_pcb, bsidesorl-v1.kicad_sch]
2026-08-13 Assign JLC part numbers (for estimated pricing)
    [bsidesorl-v1.kicad_pcb, bsidesorl-v1.kicad_sch]
2026-08-15 Update for DVT
    [BOM-bsidesorl-v1.csv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]
2026-08-15 Add holes for lanyard and SAO tether
    [CPL-bsidesorl-v1.csv, bsidesorl-v1-CuBottom.gbr, bsidesorl-v1-CuTop.gbr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]
2026-08-30 Post-prototype overhaul
    * Switch from 1x CR2032 to 2x AAs for power
    * Add a switching-mode boost circuit to get a real 3.3v rail
    * Add a 3rd SK6812 (scanning LED)
    * Add instructions to silkscreen
    * Add full-color UV art
    * Add current-limiting resistors for each self-blinking LED
    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
    [BOM-bsidesorl-v1.csv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]
2026-09-01 Final schematic, ready to order
    * Switched from 2x AAs to 1x AAA
    * Switched boost IC from TPS61023 to TPS61021A for lower VIN requirement due to single cell design change
    * Added a second capacitive touch area just because
    * Finalize back silkscreen
    [bsidesorl-v1.kicad_pcb, bsidesorl-v1.kicad_sch]
2026-09-01 Generate production files for JLCPCB
    [BOM-bsidesorl-v1.csv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]
2026-09-24 Production PCB as ordered
    * Fingerprint soldermask artwork and board outline sources
    * SW1 excluded from BOM/CPL (hand-placed)
    * Regenerated JLCPCB gerbers and production files
    * Add mk_easyeda.py for importing the KiCad board into EasyEDA Pro
    * Ignore local fab/order artifacts
    Claude-Session: https://claude.ai/code/session_01VwuCpwoY4XUvmQLYcHynUX
    [Edge.Cuts.outline.dxf, F.Mask.fingerprint.dxf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]
2026-09-29 Add EasyEDA project and exported gerbers as ordered
    In order to order a PCB from JLCPCB with full-color silkscreen, they
    require you to produce the gerbers using EasyEDA-Pro and panelizing it.
    This EasyEDA project was imported from the KiCad 10 project by using
    mk_easyeda.py to convert it into the form that EasyEDA's importer
    understands. I had to make a few minor modifications after importing
    into EasyEDA due to things like fonts not coming through perfectly. I
    also had to add the full-color silkscreen and line it up as best as I
    could, and then panelize the board. I went with a 3x5 panel. Note that
    I apparently didn't panelize it with all components, so a JLC engineer
    had to re-panelize it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
2026-09-30 Downscale programmer board image for filesize reduction
